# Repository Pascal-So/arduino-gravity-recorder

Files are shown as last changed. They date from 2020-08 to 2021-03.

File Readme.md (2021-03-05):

# Arduino Gravity Recorder

## Dependencies

* Arduino SD library
* Arduino SPI library
* Arduino Wire library
* arduino-cli
* arduino:avr core
* avr-gcc
* CMake 3.11

For the recording_parser you'll also need Eigen 3.3.

## Compilation

Setup the arduino-cli environment.

```bash
arduino-cli config init
arduino-cli core update-index
arduino-cli core install arduino:avr
arduino-cli lib install SD
```

Note that this will create the directories `~/.arduino15` and `~/Arduino`.

Check which serial port your Arduino is connected to.

```bash
arduino-cli board list
```

This next step will automatically fetch the [Arduino-CMake-Toolchain](https://github.com/a9183756-gh/Arduino-CMake-Toolchain), compile the code, and upload it to your Arduino Nano.

```bash
mkdir build
cd build
cmake -DCMAKE_BUILD_TYPE=Release ..
make

# Replace /dev/ttyUSB0 with the correct port for your setup.
make upload-arduino_gravity_recorder SERIAL_PORT=/dev/ttyUSB0
```

To compile the recording_parser:

```bash
mkdir build-parser
cd build-parser
cmake -DCMAKE_BUILD_TYPE=Release ../recording_parser
make
```

To compile and run the tests:

```bash
mkdir build-test
cd build-test
cmake -DCMAKE_BUILD_TYPE=Release ../test
make
./tests
```

## Arduino Setup

Apologies to all EE students for this ugly schematic.

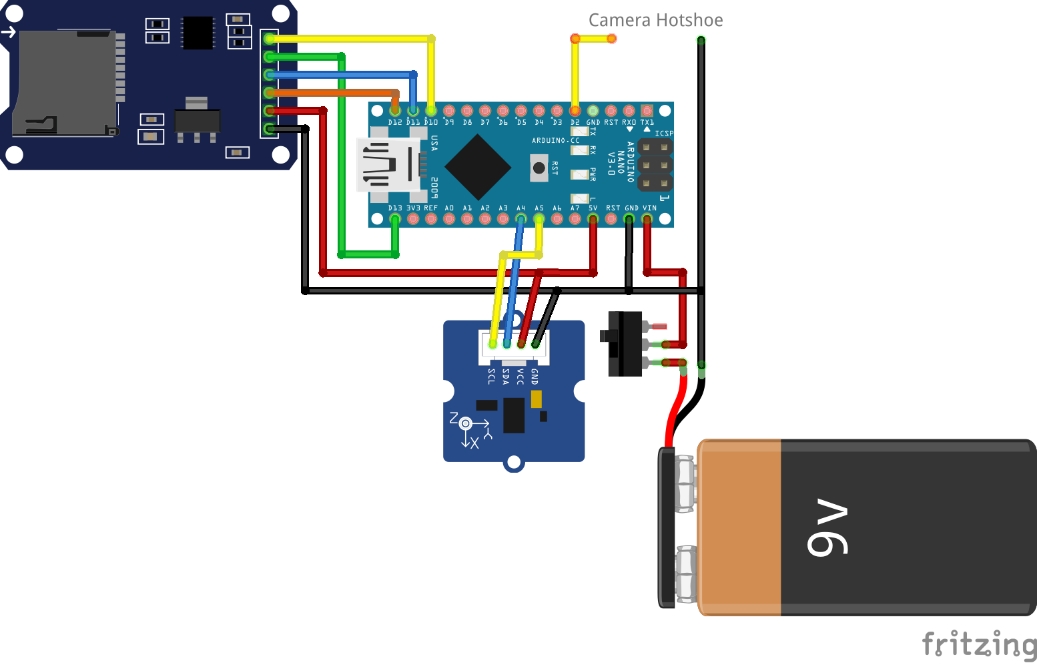
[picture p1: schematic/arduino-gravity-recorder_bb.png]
schematic


The pins on the microSD card reader, from top to bottom, are:
* CS
* SCK
* MOSI
* MISO
* VCC
* GND

This should work with any of the commonly available microSD card readers, I do however think that the IMU has to be a Grove IMU 10DOF v2, otherwise you'll have to swap out the library used in the code.

The connections at the top right should go to the camera hotshoe where the black wire (GND) goes to the U-shaped bracket and the yellow wire (D2) goes to the center pin. See ISO 10330 for more details.

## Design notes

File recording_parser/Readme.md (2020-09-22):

# Recording Parser

Calibration on Sony a7sII: 0.009561,0.009946,-0.691912,-0.721304, old -0.000052,0.022178,-0.687245,-0.726000
Calibration on Canon EOS 600D: 0.005083,0.010376,-0.693853,-0.719637

## Data Analysis

Here's a useful gnuplot palette that shows big differences for the last 4 out of 26 values.
```gnuplot
set palette model HSV defined ( 0 0 0 1, 2 0 0.5 1, 3 0 1 1, 3.5 1 1 0.2)
p 'file' u 1:2:0 with points pt 5 ps 3 palette
```

After visual inspection I think it's best to remove the last 3 points for Sony A7R photos (10ms between recordings). The shutter seems to affect the gravity recording. This was tested on a tripod with 2s delay for every photo so the problem can't be due to me shaking the camera while pressing the trigger.

### Effect of Shaky Camera

Sony a7sII, e front curtain off, Minolta 50mm lens, shaky handheld. Worst example in series of 12 photos.

Std excluding last 5 frames: 0.082219   0.113727   0.016734

Diameter of plot (visually) roughly 11deg

```gnuplot
set palette model HSV defined ( 0 0 0 0.6, 2 0 0.5 1, 3 0 1 1, 3.5 1 1 0.2)
p '009' u 1:2:0 with lines palette t "Sony a7sII handheld shaky"
```

```
 0.143899 -0.104604 -0.984048
 0.215733 -0.177248  -0.96023
 0.198328 -0.227948 -0.953261
 0.151226 -0.209839  -0.96597
0.0713005 -0.126326 -0.989423
0.0658967 0.000260461   -0.997826
0.0965698  0.091059 -0.991152
 0.178952  0.102372 -0.978517
 0.274644 0.0286143  -0.96112
 0.307444 -0.0894383  -0.947354
 0.215563 -0.184018 -0.958994
 0.150395 -0.168043  -0.97424
 0.0926461 -0.0752276  -0.992853
0.0356903 -0.00815779    -0.99933
0.0253039 -0.00971262   -0.999633
0.0400456 -0.086807  -0.99542
0.0563373 -0.220347 -0.973793
 0.075968  -0.25819 -0.963103
0.0845338 -0.277069 -0.957124
0.0655854 -0.240648 -0.968394
0.0381905  -0.16432 -0.985668
 0.039702 -0.101812 -0.994011
 0.0294451 -0.0644873  -0.997484
 0.0760183 -0.0400824  -0.996301
 0.039877 -0.0957049  -0.994611
0.0294537 -0.209063 -0.977458
```

### Expected Normal Case

Sony a7sII, e front curtain on, Minolta 50mm lens, normal handheld. Worst example in series of 6 photos.

Std excluding last 5 frames: 0.0147640   0.0086168   0.0045262

Diameter of plot (visually) roughly 2deg

```
0.0272192 -0.475948 -0.879052
0.0287551 -0.470703 -0.881823
0.00750038  -0.472266  -0.881424
-0.00411264   -0.471411   -0.881904
-0.00361978    -0.47807   -0.878314
0.00548447  -0.482373  -0.875949
 0.018922 -0.480147 -0.876984
0.0146906 -0.474033 -0.880385
0.0173772 -0.463917 -0.885708
0.00818893  -0.457524   -0.88916
-0.014445 -0.449372 -0.893228
-0.0238656  -0.455781  -0.889772
-0.0203602  -0.463131  -0.886056
-0.00595173   -0.470446   -0.882409
0.00233211  -0.481191  -0.876613
0.000258514   -0.476441   -0.879206
-0.0100998  -0.474431  -0.880235
-0.00644569   -0.472598   -0.881255
0.00388196   -0.47127  -0.881981
0.0144718  -0.46956 -0.882782
0.0211049 -0.477595 -0.878327
0.0166215 -0.479168 -0.877566
0.0133483 -0.479231 -0.877587
  0.01254 -0.478869 -0.877797
0.0103631 -0.478518 -0.878017
-0.00130162   -0.476132   -0.879373
```

### On Table, self timer

Sony a7sII, e front curtain on, Minolta 50mm lens, on table with 2s self timer. Worst example in series of 4 photos.

Std excluding last 5 frames: 0.0041189   0.0030978   0.0013623

Diameter of plot (visually) roughly 1deg

```
 0.167158 -0.319735 -0.932646
  0.16819 -0.322257 -0.931592
 0.162046 -0.321019 -0.933107
 0.162307 -0.325648 -0.931456
 0.153183 -0.324903 -0.933259
 0.157555 -0.325167 -0.932439
 0.160547 -0.323929  -0.93236
 0.170559 -0.332616 -0.927511
 0.167331 -0.327938 -0.929762
 0.166623  -0.32037 -0.932523
 0.158081  -0.32622 -0.931982
 0.161268 -0.324848 -0.931915
 0.160517 -0.319229 -0.933985
 0.161374 -0.325584  -0.93164
 0.160623 -0.320988 -0.933363
 0.164975 -0.323215 -0.931834
 0.158739 -0.323405 -0.932851
 0.160461 -0.325839 -0.931709
 0.160745 -0.326891 -0.931291
0.165164 -0.32365 -0.93165
 0.163154 -0.325532 -0.931348
 0.168212  -0.32662 -0.930067
 0.163904 -0.322413 -0.932301
 0.161486 -0.326072  -0.93145
  0.15625 -0.323883 -0.933105
 0.158986 -0.325999 -0.931906
```

### Nice visual example of shutter vibration

Sony a7sII, heavy lens (Sigma 24-70mm F2.8 DG DN Art), handheld

```
 0.0163752 -0.0844755  -0.996291
 0.0257631 -0.0855336  -0.996002
 0.0297949 -0.0880892  -0.995667
 0.033177 -0.085016 -0.995827
0.0311525 -0.082554   -0.9961
 0.0304261 -0.0808762   -0.99626
 0.0175868 -0.0848304   -0.99624
 0.0147875 -0.0706232  -0.997393
 0.0192635 -0.0773108  -0.996821
 0.0181769 -0.0729636  -0.997169
 0.0234512 -0.0693227  -0.997319
 0.0214317 -0.0748819  -0.996962
0.00748257 -0.0737936  -0.997245
0.00921031 -0.0757877  -0.997081
0.00255204 -0.0763059  -0.997081
0.00745873 -0.0889719  -0.996006
 0.0263643 -0.0616873  -0.997747
  0.031447 -0.0794037  -0.996346
 0.0347439 -0.0540178  -0.997935
 0.0417674 -0.0825036  -0.995715
 0.0160022 -0.0505877  -0.998591
0.0478785 -0.124534  -0.99106
0.00669243 -0.0447878  -0.998974
-0.0142357  -0.112543  -0.993545
-0.0485026  0.0980032  -0.994004
0.0481404 -0.136974 -0.989404
```

## Useful tools

Extract timestamps in ms from Canon images.
```bash
exiftool * | grep "Date Created" | sed -E 's/^.*([0-9]{4}):(..):(.*)$/\1-\2-\3/' | date -f - +"%s%N" | cut -c-13
```

Gravity vectors from Panda Robot ground truth.
```matlab
ee_to_camera = [0 1 0; -1 0 0; 0 0 1]
# poses is of shape n*16
vecs = (ee_to_camera * -poses(:,[3,7,11])')'
```

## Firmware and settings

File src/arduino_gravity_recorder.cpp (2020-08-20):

#include <Arduino.h>
#include <Wire.h>

#include <I2Cdev.h>
#include <MPU9250.h>

#include "cyclic_buffer.hpp"
#include "logger.hpp"

constexpr long serial_baud = 9600;
constexpr uint8_t chipselect_pin = 10;
constexpr uint8_t photo_pin = 2;
constexpr uint8_t led_pin = 6;
constexpr uint32_t clock_frequency_I2C = 400000; // 400kHz

constexpr unsigned int gravity_record_nr = 26;
constexpr unsigned long gravity_record_delay = 10; // ms

MPU9250 accelgyro;

struct gravity_state_t {
	CyclicBuffer<gravity_vector_t, gravity_record_nr> buffer;
	unsigned long next_record_time = 0;
} gravity_state;

struct photo_state_t {
	unsigned long time = 0;
	bool pending = false;
} volatile photo_state;

void photo_interrupt() {
	photo_state.time = millis();
	photo_state.pending = true;
}

struct led_state_t {
	bool on = false;
	unsigned long turnoff_time = 0;
} led_state;

void blink_led() {
	digitalWrite(led_pin, HIGH);
	led_state.on = true;
	led_state.turnoff_time = millis() + 150;
}

SDLib::File logfile;

template <typename T>
inline void serial_println(const T &t) {
#ifndef NDEBUG
	Serial.println(t);
#else
	(void)t;
#endif // NDEBUG
}

template <typename T>
inline void serial_print(const T &t) {
#ifndef NDEBUG
	Serial.print(t);
#else
	(void)t;
#endif // NDEBUG
}

void setup() {
#ifndef NDEBUG
	Serial.begin(serial_baud);
#endif // NDEBUG

	Wire.begin();
	Wire.setClock(clock_frequency_I2C);

	pinMode(led_pin, OUTPUT);
	digitalWrite(led_pin, LOW);

	pinMode(photo_pin, INPUT_PULLUP);
	attachInterrupt(digitalPinToInterrupt(photo_pin), photo_interrupt, FALLING);

	accelgyro.initialize();

	// see if the card is present and can be initialized:
	if (SDLib::SD.begin(chipselect_pin)) {
		serial_println("SD ok");

		logfile = SDLib::SD.open("gravity.txt", FILE_WRITE);

		blink_led();

	} else {
		serial_println("SD failed");

		while (true) {}
	}

	log_startup_event(millis(), logfile);
	logfile.flush();
}

// We don't calibrate the data on the Arduino itself (mostly
// because I don't feel like implementing this without having
// Eigen at hand), instead we just store the raw data from the
// sensor to the SD card.
void get_acc(gravity_vector_t &vec) {
	accelgyro.getAcceleration(&vec[0], &vec[1], &vec[2]);
	// serial_print(vec[0]);
	// serial_print(' ');
	// serial_print(vec[1]);
	// serial_print(' ');
	// serial_println(vec[2]);
}

void loop() {
	const unsigned long millis_at_iter_start = millis();

	// Record gravity vectors
	if (millis_at_iter_start > gravity_state.next_record_time) {
		gravity_state.next_record_time =
		    millis_at_iter_start + gravity_record_delay;
		get_acc(gravity_state.buffer.push());
	}

	// Check LED state
	if (led_state.on && millis_at_iter_start > led_state.turnoff_time) {
		led_state.on = false;
		digitalWrite(led_pin, LOW);
	}

	// Handle a photo event -> write info to SD
	if (photo_state.pending) {
		// Write gravity vectors and current time to sd. The whole
		// writing and flushing together seems to take between 18
		// and 24 milliseconds.
		for (unsigned long i = 0; i < gravity_state.buffer.size(); ++i)
			log_gravity_vector(gravity_state.buffer[i], logfile);
		log_photo_event(photo_state.time, logfile);

		photo_state.pending = false;

		logfile.flush();

		gravity_state.buffer.clear();
		gravity_state.next_record_time = 0;

		serial_println("photo");
		blink_led();
	}
}

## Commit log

2020-08-10 add schematic
    [arduino-gravity-recorder.fzz]
2020-08-10 actually read ISO 10330, apparently polarity does matter for some cameras
2020-08-20 blink led on photo
2020-09-10 update schematic
    [arduino-gravity-recorder.fzz]
2020-09-22 fix calibration
2021-03-05 skip photos with less than 3 samples
